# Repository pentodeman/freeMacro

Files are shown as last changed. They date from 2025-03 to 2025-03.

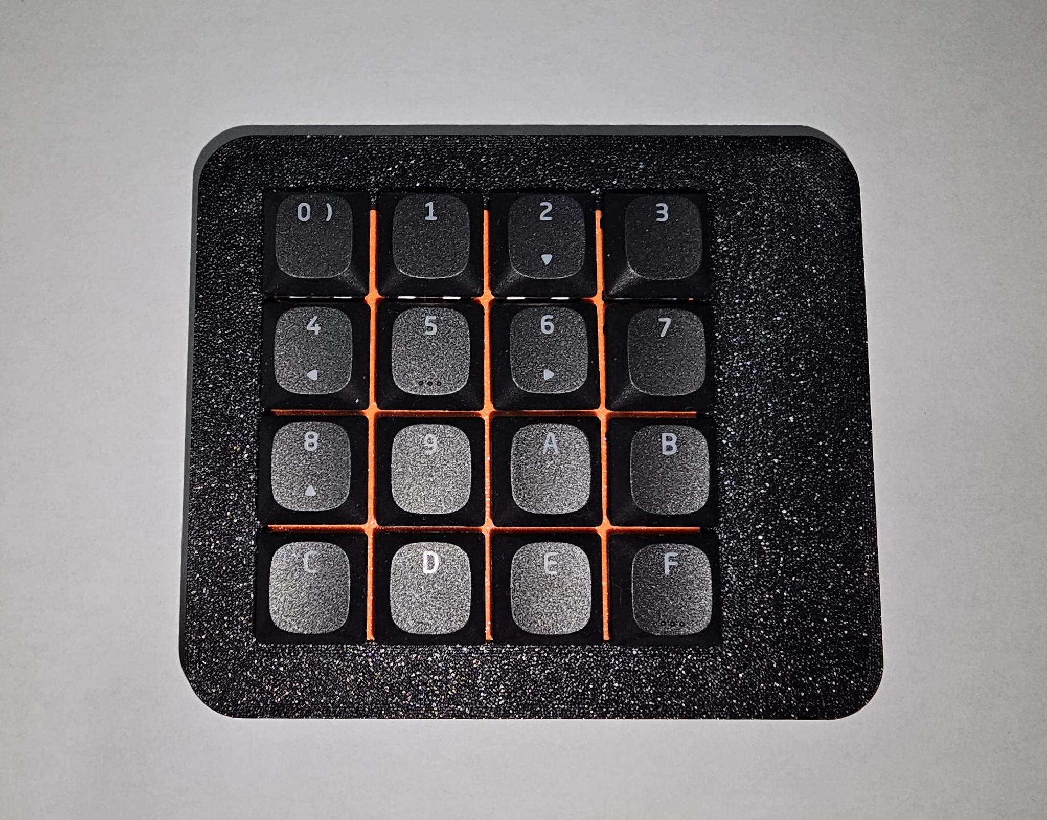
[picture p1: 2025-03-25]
images/Plate_Top_View.jpeg

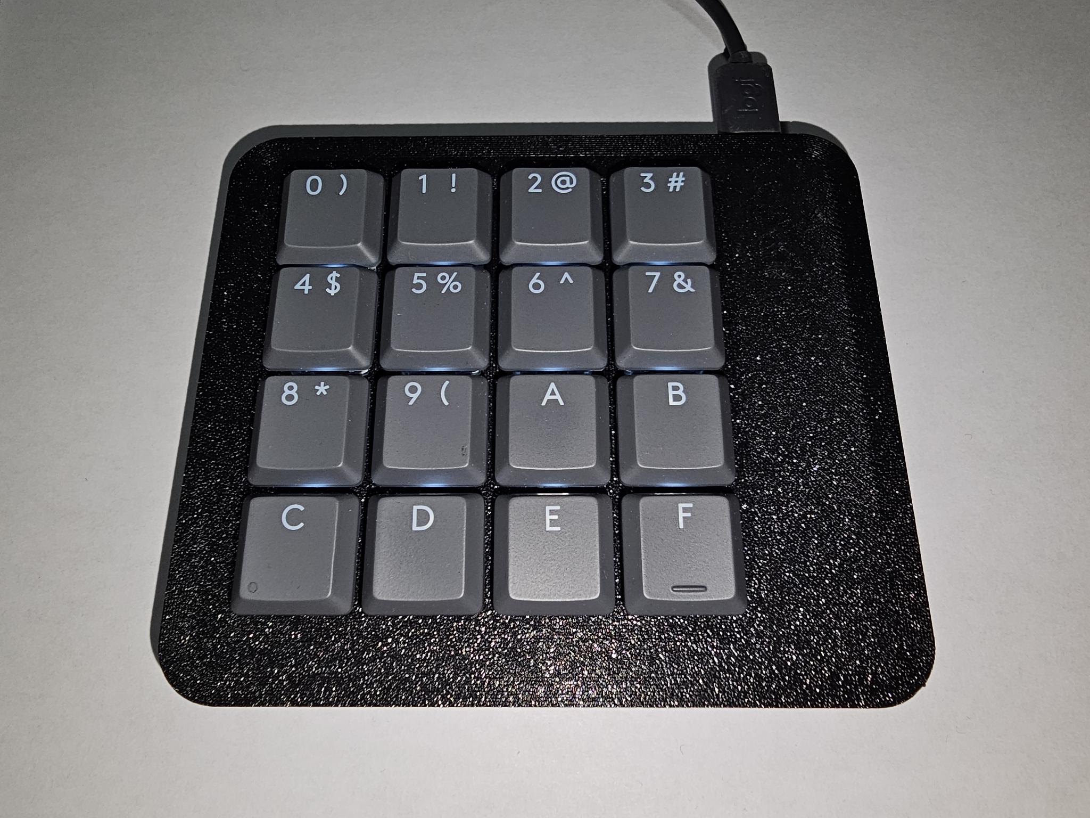
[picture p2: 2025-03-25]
images/Plateless_Top_Angle_View.jpeg

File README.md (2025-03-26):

# freeMacro rev. 1
A simple macro keypad that invokes key combinations, prints strings of text, and types special characters.

Special thanks to Arduino LLC for providing the Keyboard library that was used to create this project.
The library is available under:
https://github.com/arduino-libraries/Keyboard

## Features
* Typing strings, invoking macros, and typing special characters from the Unicode table
* 13 assignable banks with combinations of all three types of keypresses
* On the fly assignment of target operating system (Linux, Windows, macOS)
* Dependency free, plug and play
* Config generation handled by genConfig

## Default Firmware Behavior
* On power on, the board will flash each LED individually from the F key to the 0 key.
* Idle backlight should be steady without any flickering.
* On each keypress, only that key will be lit. Others will not.
* Holding down any key from 0 to C changes the current bank to that of they key held down.
* Pressing a key will invoke its macro (key combo, string, or Unicode).
* Holding down keys from D to F will change the target operating system:
  * D: Linux
  * E: Windows
  * F: macOS
* The default config initializes the bank to 9 and OS to Linux, if you prefer to use another combination, edit "banks.layout" and run genConfig (more instructions later).
* Bank and OS changes are indicated by the flash pattern:
  * fast: bank change
  * slow: OS change

## Modifying the config
* The firmware consists of two files:
  * freeMacro-firmware.ino: main firmware file that handles the logic
  * config.h: header file that houses all the functions called on keystrokes -> this is the config file
* Option 1: you can edit config.h directly if you want more control over your device (make sure to back up the default config in case of a rollback).
* Option 2: use genConfig and edit the soft config file (banks.layout).

## Arduino IDE is required for uploading the firmware (or Arduino CLI)
* Pro Micro boards are usually miniaturized Arduino Leonardos, selecting Arduino Leonardo in your board manager will likely work.
* In case of upload issues, make sure you selected the correct board and plugged it in. Communication issues can be caused by the serial port being busy or not having permissions to use the port (Googling the programmer error will usually solve the issue).

## Using genConfig
* This repo provides the source code for genConfig and a Linux binary.
* This program was only tested on Linux. Windows or macOS users may need to make changes to the source code, but this is unlikely. If you're using one of these systems, try compiling it first. For this you will need a C++ compiler. I used g++.
* Compiling genConfig from source:
  * This program does not use any third-party dependencies.
  * The only requirement for compilation is the C++ compiler itself; g++ is recommended.
  * To compile the program, follow these steps:
  
    ```git clone https://github.com/pentodeman/freeMacro```
    
    ```cd freeMacro```

    ```g++ genConfig.cpp -o genConfig```

    ```./genConfig --help```
  * It is not recommended to add genConfig to any binary directories (/bin, /sbin, /usr/bin, /usr/sbin, etc...) as the program outputs the file to its current working directory.
  * genConfig will look for the file called banks.layout in its current working directory and will output config.h
  * To generate a new config simply run:

    ```./genConfig``` for silent generation

    or

    ```./genConfig -v``` or ```./genConfig --verbose``` for verbose generation.
  * To use the new config, move the new config.h to the "freeMacro-firmware" directory and replace the old one (backing up your configs is recommended).
  * Once the new config.h is placed in the firmware directory, open the .ino file in Arduino IDE and upload it to your freeMacro board.
  * Instructions for modifying banks.layout are in the file itself and include a general template with all possible keywords.

## Assembly
* Required materials:
  * 1 PCB **make sure the PCB thickness is 1.6 mm** (Gerber files attached)
  * 16 3-pin full size mechanical switches of any kind (5-pin update coming soon in revision 2)
  * Electronic components listed in the BOM
  * 3D printed case (.stl files attached; feel free to design your own (.step file of the PCB can be generated in KiCad))
  * Low profile keycaps (currently full size keycaps have clearance issues with the enclosure)
* Tips for soldering the PCB:
  1. Start with the smallest and most repetitive components first (all passive and discrete components on the top plane).
  2. Solder the two multiplexer ICs.
  3. Clean the PCB thoroughly with isopropanol.
  4. Then solder the bottom LED current limiting resistors and clean the board again.
  5. Solder the Arduino Pro Micro FLUSH with the PCB. The case is designed to fit the microcontroller soldered directly to the PCB using included headers (see images folder).
    * feed the headers from the bottom of the freeMacro PCB and place the Arduino on top.
  6. After all electronic components are soldered, test the board by bridging switch pads with tweezers or any other conductor. Open any text editor and check if all characters are printed. Bank 9 of the default config is a good test.
  7. Once everything works, solder the switches. If you use the top shell with the plate, print the plate first and populate it with switches. It works as a good soldering guide. Make sure to test fit the entire device before soldering the switches.
  8. After soldering the switches, feed the LEDs throughand solder them. It's a good idea to just feed them and bend the leads for testing. Do it and plug in the board. If you see all LEDs shining (with some wiggling due to the lack of solder), the board works.
  9. Trim the leads, clean the board one last time, and assemble the case.
  10. Your board is ready, it's a good time to double check everything.

### Please note that this project is not a polished product. It's meant to be a fun project to tinker and experiment with. Working on it took me a total of one week worth of deisgn, coding, assembly, and testing. Please take imperfections with a grain of salt, as this is only a project delivered by a nerd to his fellow nerds. Happy tinkering!

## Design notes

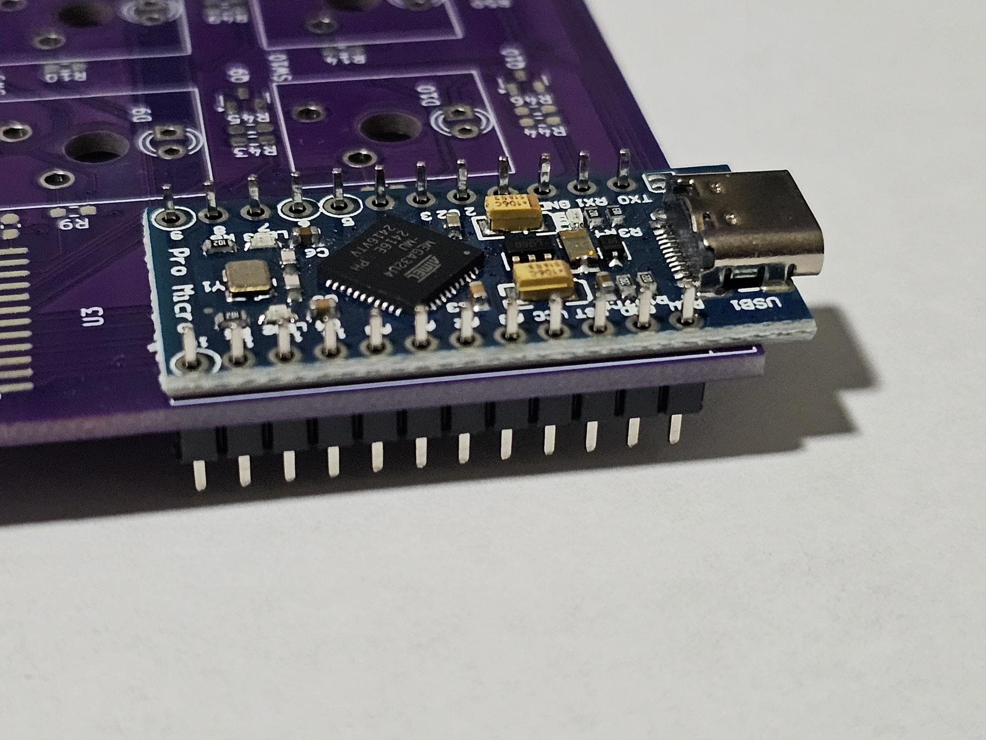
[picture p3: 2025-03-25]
images/Microcontroller_Placement.jpeg

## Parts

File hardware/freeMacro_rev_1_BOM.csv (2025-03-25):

Reference | Value | Datasheet | Footprint | Qty | DNP
C1,C2 | 100nF | ~ | Capacitor_SMD:C_0603_1608Metric_Pad1.08x0.95mm_HandSolder | 2
D1,D2,D3,D4,D5,D6,D7,D8,D9,D10,D11,D12,D13,D14,D15,D16 | LED | ~ | LED_THT:LED_D3.0mm | 16
Q1,Q2,Q3,Q4,Q5,Q6,Q7,Q8,Q9,Q10,Q11,Q12,Q13,Q14,Q15,Q16 | 2N7002 | https://www.onsemi.com/pub/Collateral/NDS7002A-D.PDF | Package_TO_SOT_SMD:SOT-23 | 16
R1,R2,R3,R4,R5,R6,R7,R8,R9,R10,R11,R12,R13,R14,R15,R16,R17,R18 | 10k | ~ | Resistor_SMD:R_0603_1608Metric_Pad0.98x0.95mm_HandSolder | 18
R19,R23,R26,R29,R32,R35,R38,R41,R45,R46,R51,R52,R57,R58,R63,R64 | 100k | ~ | Resistor_SMD:R_0603_1608Metric_Pad0.98x0.95mm_HandSolder | 16
R20,R22,R25,R28,R31,R34,R37,R40,R43,R44,R49,R50,R55,R56,R61,R62 | 10 | ~ | Resistor_SMD:R_0603_1608Metric_Pad0.98x0.95mm_HandSolder | 16
R21,R24,R27,R30,R33,R36,R39,R42,R47,R48,R53,R54,R59,R60,R65,R66 | 200 | ~ | Resistor_SMD:R_0603_1608Metric_Pad0.98x0.95mm_HandSolder | 16
U1,U2 | CD74HC4067M | http://www.ti.com/lit/ds/symlink/cd74hc4067.pdf | Package_SO:SOIC-24W_7.5x15.4mm_P1.27mm | 2

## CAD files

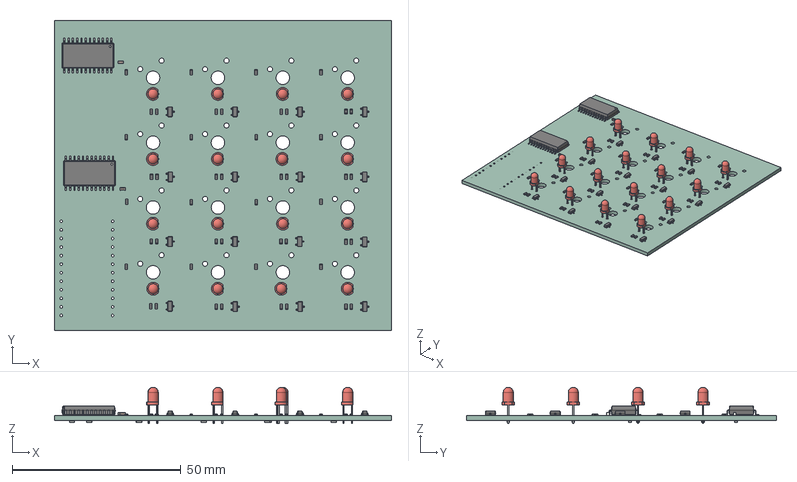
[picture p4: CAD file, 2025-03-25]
enclosure/freeMacro_rev_1_board.step
100.0 x 92.0 x 10.8 mm
R_0603_1608Metric x 66
LED_D3.0mm x 16
SOT-23 x 16
SOIC-24W_7.5x15.4mm_P1.27mm x 2
C_0603_1608Metric x 2
Macro Keyboard V1_PCB

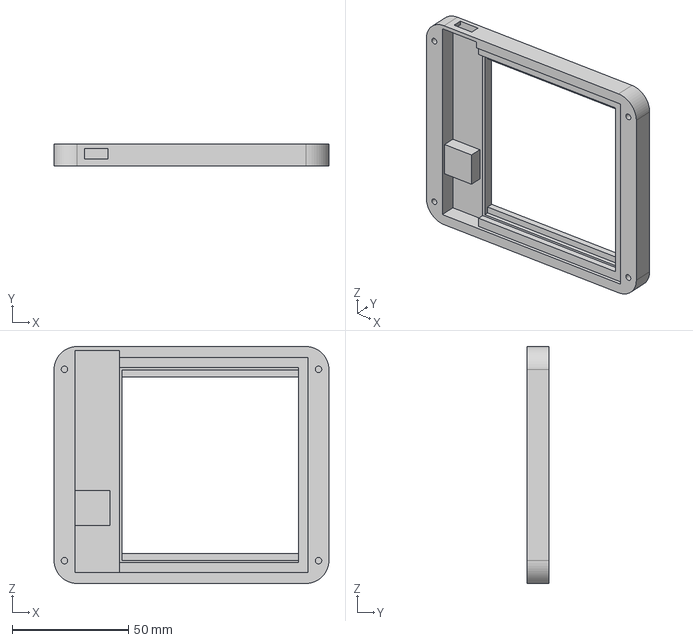
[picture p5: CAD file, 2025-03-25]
enclosure/Case Top.step
118.4 x 9.64 x 102.0 mm

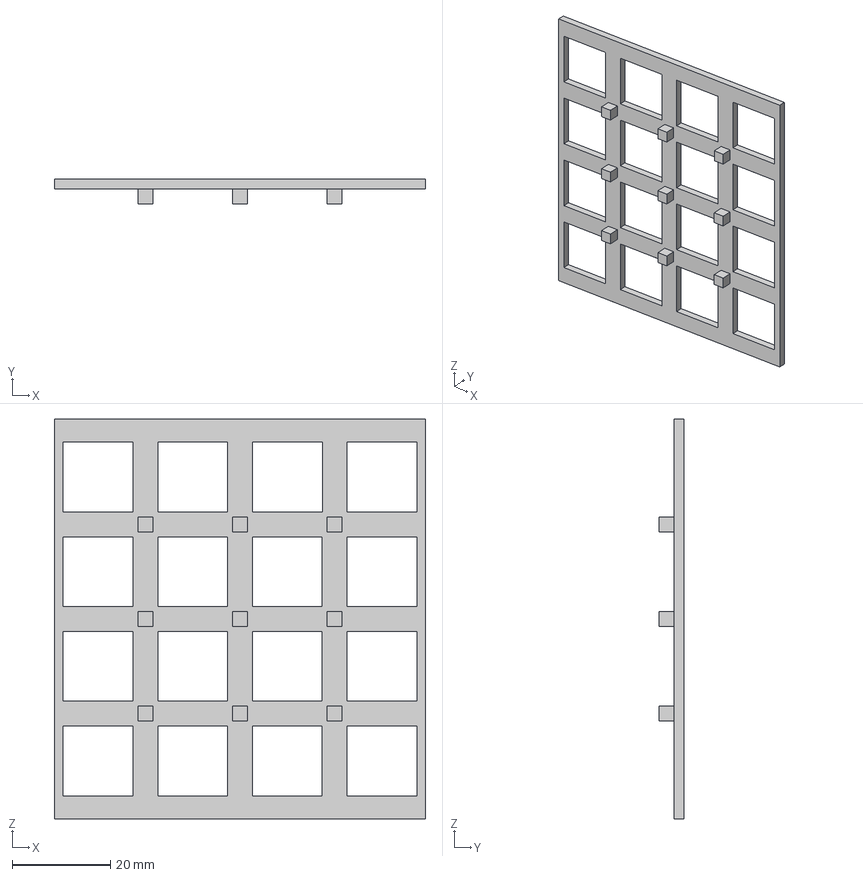
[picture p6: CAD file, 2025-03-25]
enclosure/Plate.step
75.5 x 5.00 x 81.3 mm

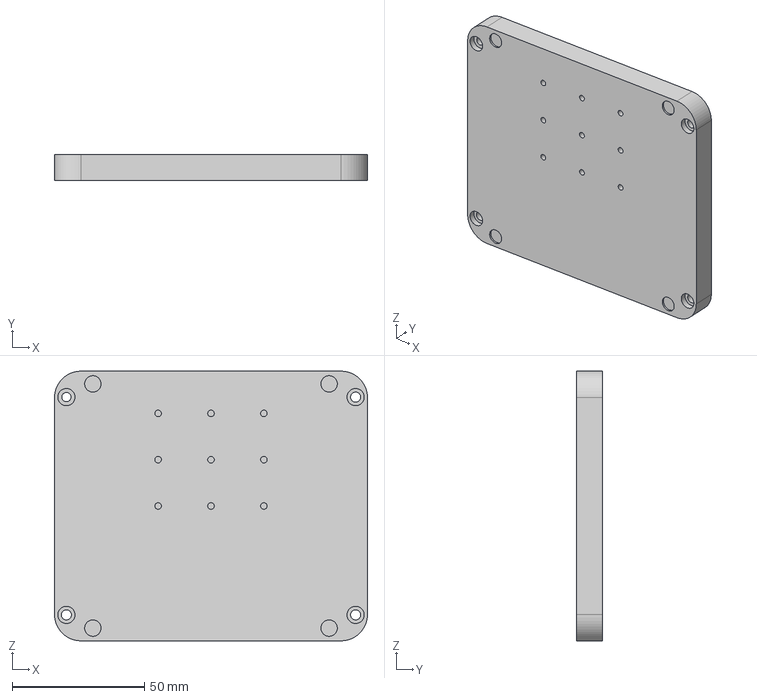
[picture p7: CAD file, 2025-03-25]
enclosure/Case Bottom.step
118.4 x 10.0 x 102.0 mm

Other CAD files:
enclosure/Case Bottom.stl
enclosure/Case Top.stl
enclosure/Plate.stl

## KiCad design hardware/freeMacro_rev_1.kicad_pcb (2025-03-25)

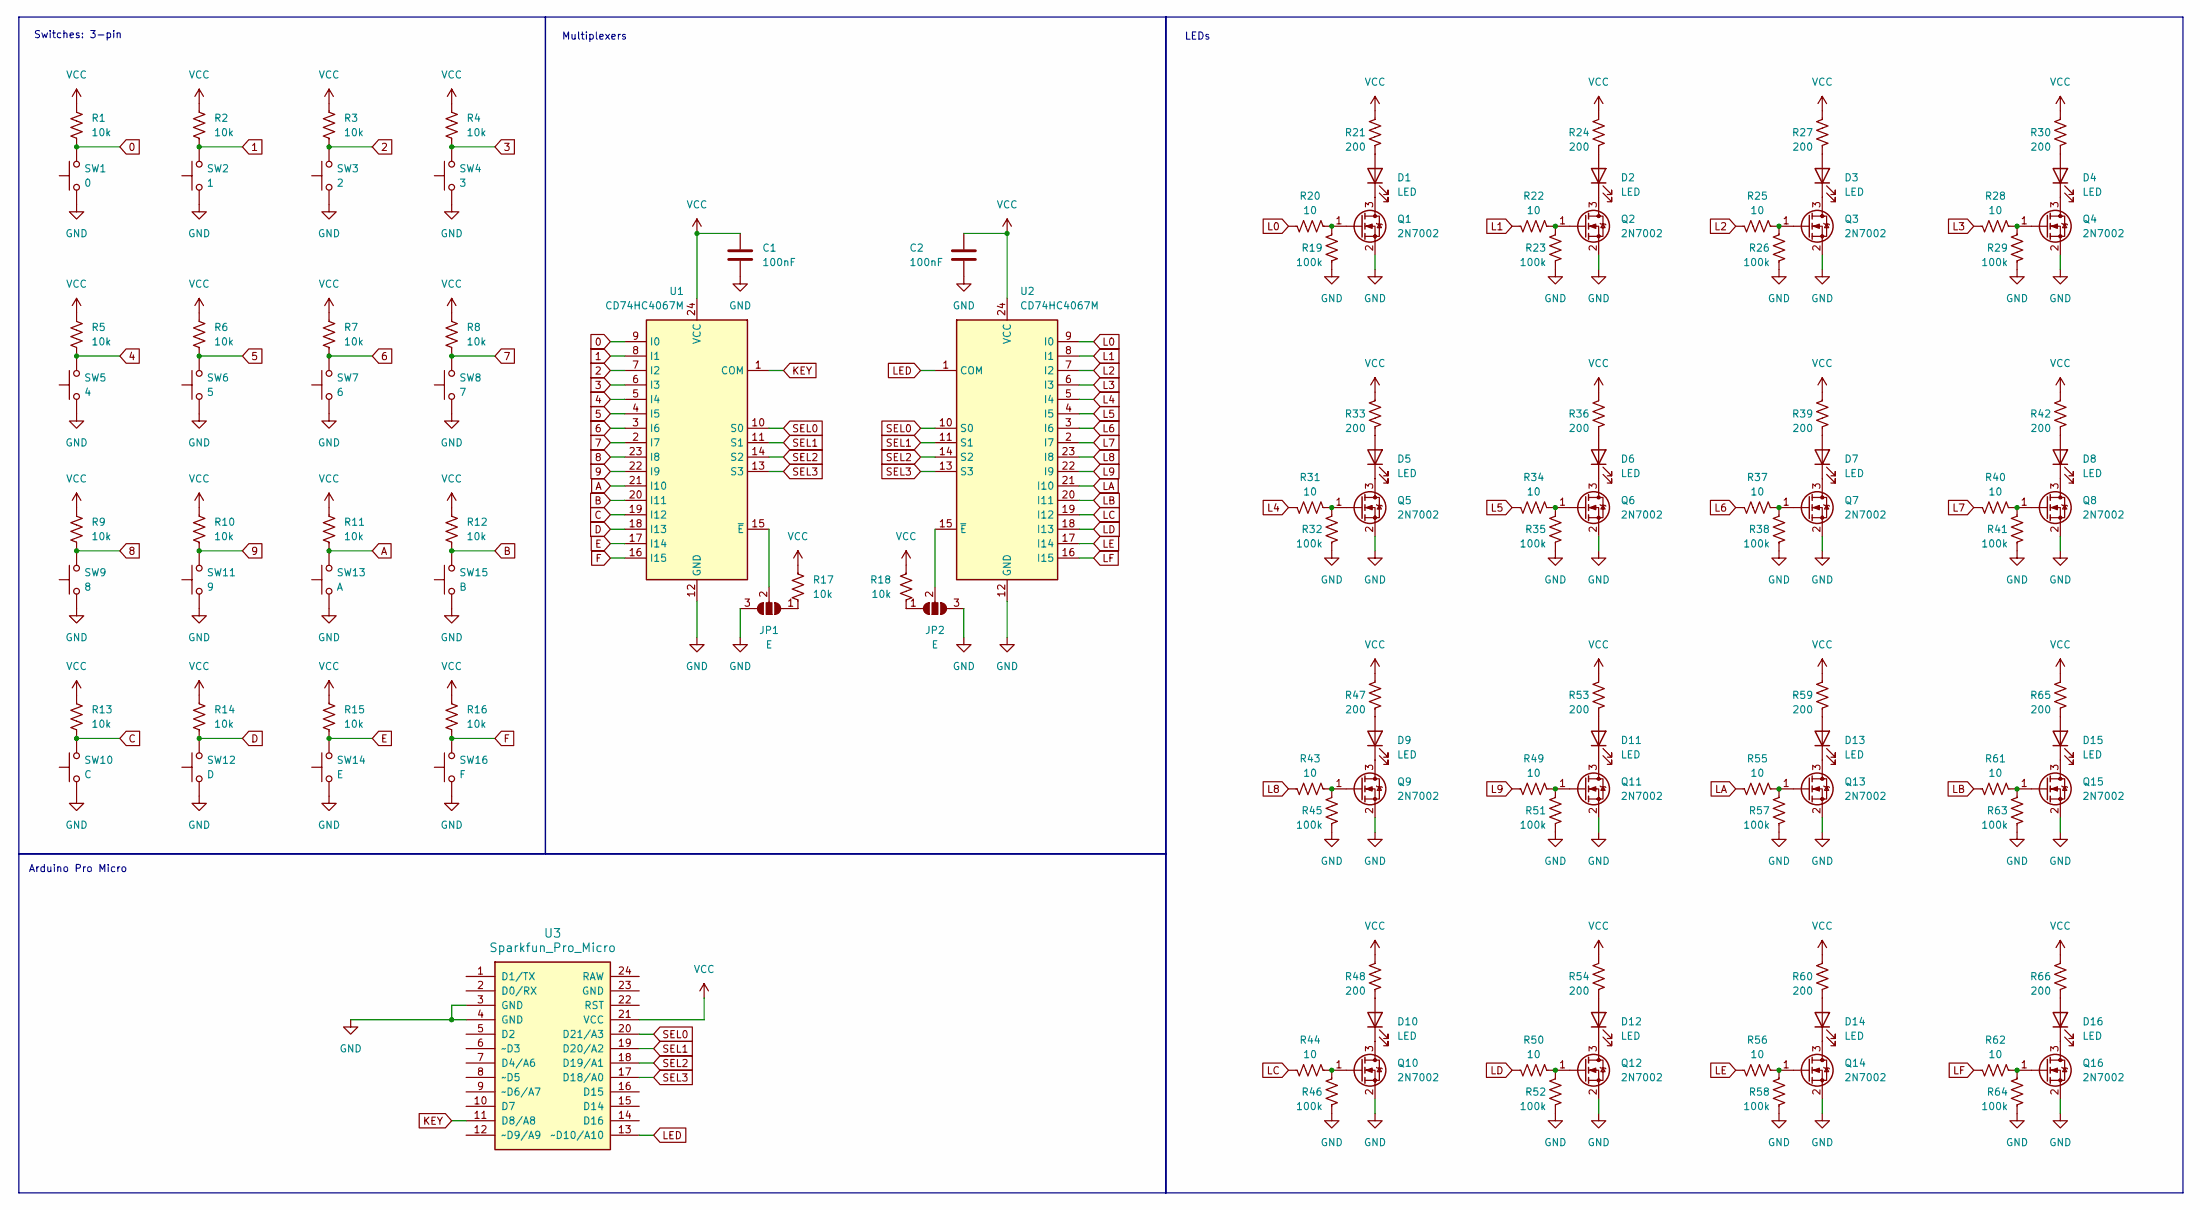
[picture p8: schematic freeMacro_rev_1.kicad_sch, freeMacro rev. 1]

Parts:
C1, C2: 100nF; C_0603_1608Metric_Pad1.08x0.95mm_HandSolder
D1, D2, D3, D4, D5, D6, D7, D8, D9, D10, D11, D12, D13, D14, D15, D16: LED; LED_D3.0mm
JP1, JP2: E; SolderJumper-3_P2.0mm_Open_TrianglePad1.0x1.5mm
Q1, Q2, Q3, Q4, Q5, Q6, Q7, Q8, Q9, Q10, Q11, Q12, Q13, Q14, Q15, Q16: 2N7002; SOT-23
R1, R2, R3, R4, R5, R6, R7, R8, R9, R10, R11, R12, R13, R14, R15, R16, R17, R18: 10k; R_0603_1608Metric_Pad0.98x0.95mm_HandSolder
R19, R23, R26, R29, R32, R35, R38, R41, R45, R46, R51, R52, R57, R58, R63, R64: 100k; R_0603_1608Metric_Pad0.98x0.95mm_HandSolder
R20, R22, R25, R28, R31, R34, R37, R40, R43, R44, R49, R50, R55, R56, R61, R62: 10; R_0603_1608Metric_Pad0.98x0.95mm_HandSolder
R21, R24, R27, R30, R33, R36, R39, R42, R47, R48, R53, R54, R59, R60, R65, R66: 200; R_0603_1608Metric_Pad0.98x0.95mm_HandSolder
SW1: 0; SW_Cherry_MX_1.00u_Plate
SW2: 1; SW_Cherry_MX_1.00u_Plate
SW3: 2; SW_Cherry_MX_1.00u_Plate
SW4: 3; SW_Cherry_MX_1.00u_Plate
SW5: 4; SW_Cherry_MX_1.00u_Plate
SW6: 5; SW_Cherry_MX_1.00u_Plate
SW7: 6; SW_Cherry_MX_1.00u_Plate
SW8: 7; SW_Cherry_MX_1.00u_Plate
SW9: 8; SW_Cherry_MX_1.00u_Plate
SW10: C; SW_Cherry_MX_1.00u_Plate
SW11: 9; SW_Cherry_MX_1.00u_Plate
SW12: D; SW_Cherry_MX_1.00u_Plate
SW13: A; SW_Cherry_MX_1.00u_Plate
SW14: E; SW_Cherry_MX_1.00u_Plate
SW15: B; SW_Cherry_MX_1.00u_Plate
SW16: F; SW_Cherry_MX_1.00u_Plate
U1, U2: CD74HC4067M; SOIC-24W_7.5x15.4mm_P1.27mm
U3: Sparkfun_Pro_Micro

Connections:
0: R1.2, SW1.2, U1.9 (I0)
1: R2.2, SW2.2, U1.8 (I1)
2: R3.2, SW3.2, U1.7 (I2)
3: R4.2, SW4.2, U1.6 (I3)
4: R5.2, SW5.2, U1.5 (I4)
5: R6.2, SW6.2, U1.4 (I5)
6: R7.2, SW7.2, U1.3 (I6)
7: R8.2, SW8.2, U1.2 (I7)
8: R9.2, SW9.2, U1.23 (I8)
9: R10.2, SW11.2, U1.22 (I9)
A: R11.2, SW13.2, U1.21 (I10)
B: R12.2, SW15.2, U1.20 (I11)
C: R13.2, SW10.2, U1.19 (I12)
D: R14.2, SW12.2, U1.18 (I13)
E: R15.2, SW14.2, U1.17 (I14)
F: R16.2, SW16.2, U1.16 (I15)
GND: C1.2, C2.2, JP1.3 (B), JP2.3 (B), Q1.2 (S), Q2.2 (S), Q3.2 (S), Q4.2 (S), Q5.2 (S), Q6.2 (S), Q7.2 (S), Q8.2 (S), Q9.2 (S), Q10.2 (S), Q11.2 (S), Q12.2 (S), Q13.2 (S), Q14.2 (S), Q15.2 (S), Q16.2 (S), R19.2, R23.2, R26.2, R29.2, R32.2, R35.2, R38.2, R41.2, R45.2, R46.2, R51.2, R52.2, R57.2, R58.2, R63.2, R64.2, SW1.1, SW2.1, SW3.1, SW4.1, SW5.1, SW6.1, SW7.1, SW8.1, SW9.1, SW10.1, SW11.1, SW12.1, SW13.1, SW14.1, SW15.1, SW16.1, U1.12 (GND), U2.12 (GND), U3.3 (GND), U3.4 (GND)
KEY: U1.1 (COM), U3.11 (D8/A8)
L0: R20.1, U2.9 (I0)
L1: R22.1, U2.8 (I1)
L2: R25.1, U2.7 (I2)
L3: R28.1, U2.6 (I3)
L4: R31.1, U2.5 (I4)
L5: R34.1, U2.4 (I5)
L6: R37.1, U2.3 (I6)
L7: R40.1, U2.2 (I7)
L8: R43.1, U2.23 (I8)
L9: R49.1, U2.22 (I9)
LA: R55.1, U2.21 (I10)
LB: R61.1, U2.20 (I11)
LC: R44.1, U2.19 (I12)
LD: R50.1, U2.18 (I13)
LE: R56.1, U2.17 (I14)
LED: U2.1 (COM), U3.13 (~D10/A10)
LF: R62.1, U2.16 (I15)
unnamed: D1.2 (A), R21.2
unnamed: D1.1 (K), Q1.3 (D)
unnamed: D2.2 (A), R24.2
unnamed: D2.1 (K), Q2.3 (D)
unnamed: D3.2 (A), R27.2
unnamed: D3.1 (K), Q3.3 (D)
unnamed: D4.2 (A), R30.2
unnamed: D4.1 (K), Q4.3 (D)
unnamed: D5.2 (A), R33.2
unnamed: D5.1 (K), Q5.3 (D)
unnamed: D6.2 (A), R36.2
unnamed: D6.1 (K), Q6.3 (D)
unnamed: D7.2 (A), R39.2
unnamed: D7.1 (K), Q7.3 (D)
unnamed: D8.2 (A), R42.2
unnamed: D8.1 (K), Q8.3 (D)
unnamed: D9.2 (A), R47.2
unnamed: D9.1 (K), Q9.3 (D)
unnamed: D10.2 (A), R48.2
unnamed: D10.1 (K), Q10.3 (D)
unnamed: D11.2 (A), R53.2
unnamed: D11.1 (K), Q11.3 (D)
unnamed: D12.2 (A), R54.2
unnamed: D12.1 (K), Q12.3 (D)
unnamed: D13.2 (A), R59.2
unnamed: D13.1 (K), Q13.3 (D)
unnamed: D14.2 (A), R60.2
unnamed: D14.1 (K), Q14.3 (D)
unnamed: D15.2 (A), R65.2
unnamed: D15.1 (K), Q15.3 (D)
unnamed: D16.2 (A), R66.2
unnamed: D16.1 (K), Q16.3 (D)
unnamed: JP1.1 (A), R17.2
unnamed: JP1.2 (C), U1.15 (~E)
unnamed: JP2.1 (A), R18.2
unnamed: JP2.2 (C), U2.15 (~E)
unnamed: Q1.1 (G), R19.1, R20.2
unnamed: Q2.1 (G), R22.2, R23.1
unnamed: Q3.1 (G), R25.2, R26.1
unnamed: Q4.1 (G), R28.2, R29.1
unnamed: Q5.1 (G), R31.2, R32.1
unnamed: Q6.1 (G), R34.2, R35.1
unnamed: Q7.1 (G), R37.2, R38.1
unnamed: Q8.1 (G), R40.2, R41.1
unnamed: Q9.1 (G), R43.2, R45.1
unnamed: Q10.1 (G), R44.2, R46.1
unnamed: Q11.1 (G), R49.2, R51.1
unnamed: Q12.1 (G), R50.2, R52.1
unnamed: Q13.1 (G), R55.2, R57.1
unnamed: Q14.1 (G), R56.2, R58.1
unnamed: Q15.1 (G), R61.2, R63.1
unnamed: Q16.1 (G), R62.2, R64.1
SEL0: U1.10 (S0), U2.10 (S0), U3.20 (D21/A3)
SEL1: U1.11 (S1), U2.11 (S1), U3.19 (D20/A2)
SEL2: U1.14 (S2), U2.14 (S2), U3.18 (D19/A1)
SEL3: U1.13 (S3), U2.13 (S3), U3.17 (D18/A0)
VCC: C1.1, C2.1, R1.1, R2.1, R3.1, R4.1, R5.1, R6.1, R7.1, R8.1, R9.1, R10.1, R11.1, R12.1, R13.1, R14.1, R15.1, R16.1, R17.1, R18.1, R21.1, R24.1, R27.1, R30.1, R33.1, R36.1, R39.1, R42.1, R47.1, R48.1, R53.1, R54.1, R59.1, R60.1, R65.1, R66.1, U1.24 (VCC), U2.24 (VCC), U3.21 (VCC)

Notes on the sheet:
Multiplexers
Switches: 3-pin
LEDs
Arduino Pro Micro

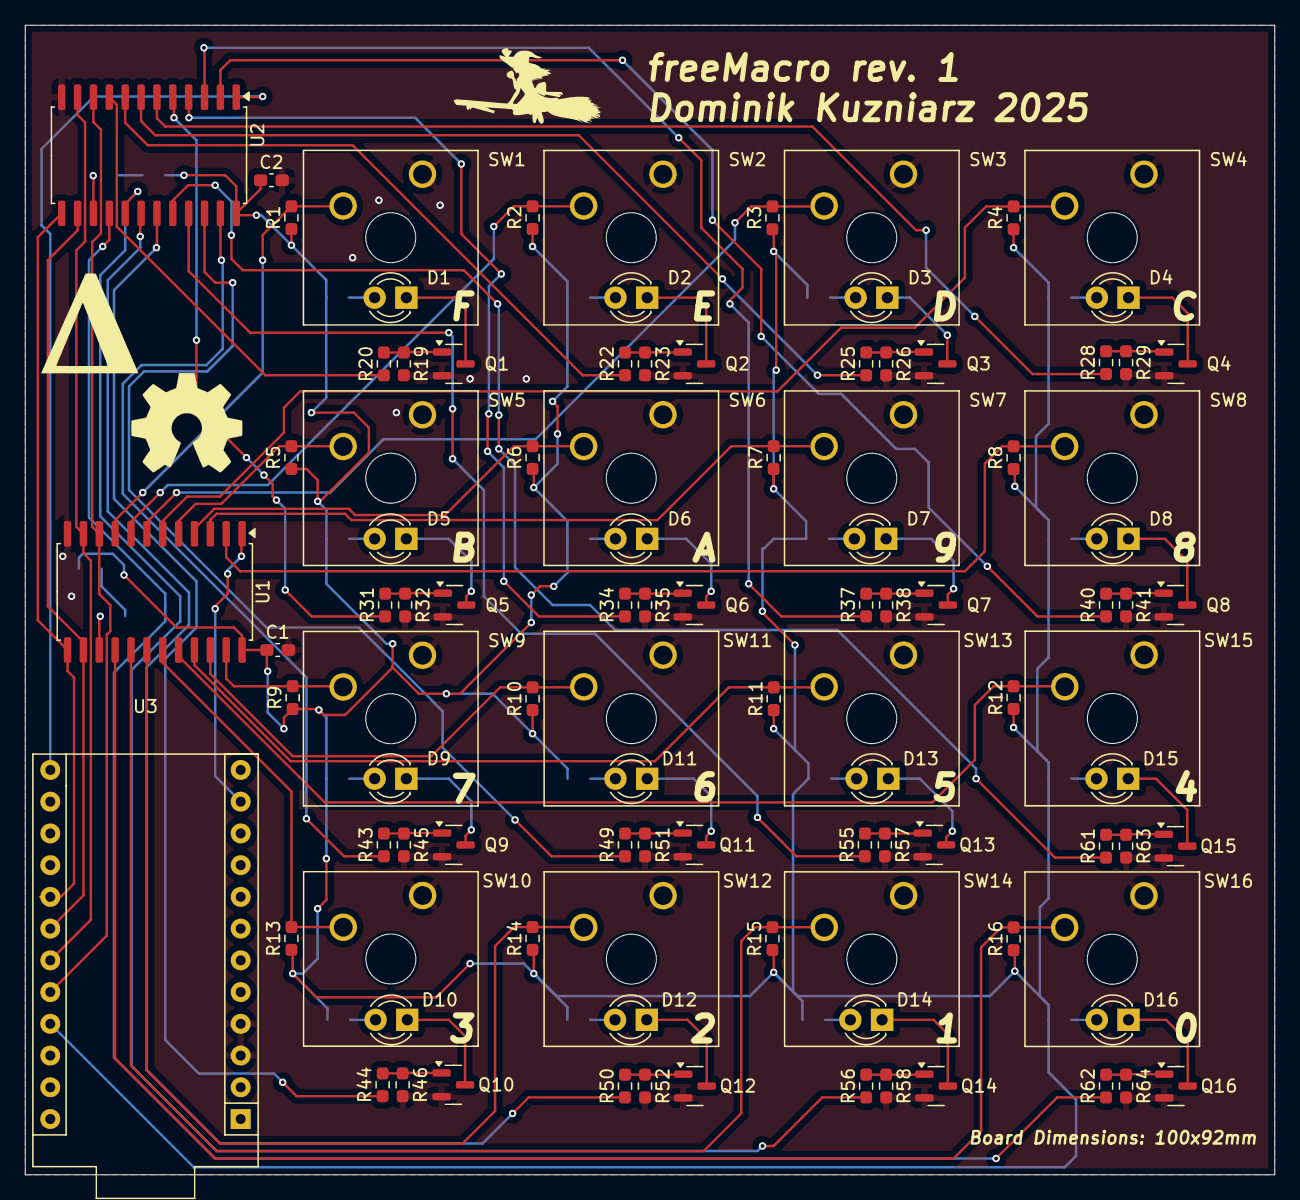
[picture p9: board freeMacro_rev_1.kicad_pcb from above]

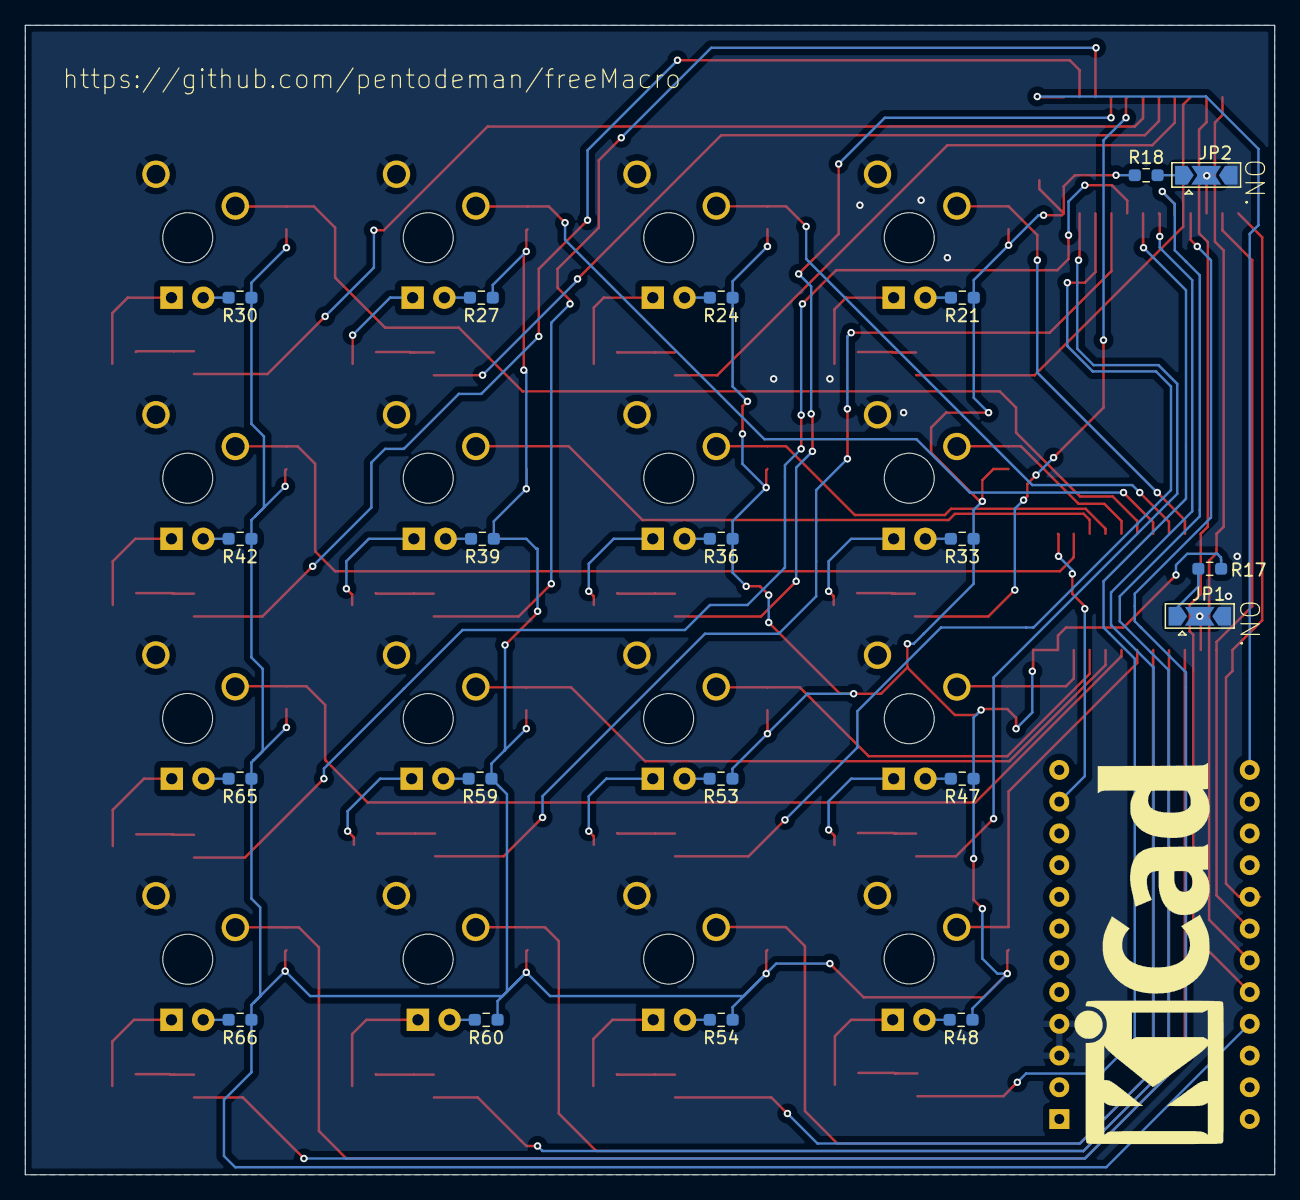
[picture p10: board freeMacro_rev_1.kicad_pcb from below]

Board: 2 copper layers, 100.0 x 92.0 mm, 121 parts (20 on the bottom side), 92 nets.

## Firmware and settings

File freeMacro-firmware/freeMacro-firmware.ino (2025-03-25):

// freeMacro firmware v0.5
// Dominik Kuzniarz 2025

#include "config.h"
#include "Keyboard.h"
#define LEDOUT 10
#define KEYIN 8

long lastKeyTime = 0;
long currentKeyTime = 0;

void animation(){
  for(uint8_t i = 0; i < 16; i++){
    uint8_t select = i << 4;
    PORTF = select;
    uint8_t brt;
    for(brt = 0; brt < 255; brt++){
      analogWrite(LEDOUT, brt);
      delayMicroseconds(50);
    }
    for(brt = 255; brt > 0; brt--){
      analogWrite(LEDOUT, brt);
      delayMicroseconds(500);
    }
  }
}

void bankFlash(uint8_t sel){
  uint8_t select = sel << 4;
  PORTF = select;
  for(uint8_t i = 0; i < 7; i++){
    uint8_t brt;
    for(brt = 0; brt < 255; brt++){
      analogWrite(LEDOUT, brt);
      delayMicroseconds(400);
    }
    for(brt = 255; brt > 0; brt--){
      analogWrite(LEDOUT, brt);
      delayMicroseconds(400);
    }
  }
}

void bankFlashOS(uint8_t sel){
  uint8_t select = sel << 4;
  PORTF = select;
  for(uint8_t i = 0; i < 5; i++){
    uint8_t brt;
    for(brt = 0; brt < 255; brt++){
      analogWrite(LEDOUT, brt);
      delayMicroseconds(2000);
    }
    for(brt = 255; brt > 0; brt--){
      analogWrite(LEDOUT, brt);
      delayMicroseconds(10);
    }
  }
}

void bankSelectFeedback(uint8_t bank){
  switch(bank){
    case 0x00: bankFlash(0x00); break;
    case 0x01: bankFlash(0x01); break;
    case 0x02: bankFlash(0x02); break;
    case 0x03: bankFlash(0x03); break;
    case 0x04: bankFlash(0x04); break;
    case 0x05: bankFlash(0x05); break;
    case 0x06: bankFlash(0x06); break;
    case 0x07: bankFlash(0x07); break;
    case 0x08: bankFlash(0x08); break;
    case 0x09: bankFlash(0x09); break;
    case 0x0A: bankFlash(0x0A); break;
    case 0x0B: bankFlash(0x0B); break;
    case 0x0C: bankFlash(0x0C); break;
    case 0x0D: bankFlash(0x0D); break;
    case 0x0E: bankFlash(0x0E); break;
    case 0x0F: bankFlash(0x0F); break;
  }
}

void key(uint8_t keyPressed){
  lastKeyTime = millis();
  while(digitalRead(KEYIN) == LOW){
    currentKeyTime = millis();
    if(currentKeyTime - lastKeyTime >= HOLD_THRESHOLD){
      currentKeyTime = 0;
      lastKeyTime = 0;
      checkKeyHold(keyPressed);
    }
  }
  if(currentKeyTime - lastKeyTime >= DEBOUNCE_TIME){
    currentKeyTime = 0;
    lastKeyTime = 0;
    checkKeyPress(keyPressed);
  }
}

void setup() {
  pinMode(LEDOUT, OUTPUT);
  pinMode(KEYIN, INPUT);
  DDRF = DDRF | 0xFF;          // set all PF pins as output
  Keyboard.begin();
  animation();
}

void checkKeyHold(uint8_t sel){
  switch(sel){
    case 0x00: currentOS = 0x02; bankFlashOS(0x00); break;
    case 0x01: currentOS = 0x01; bankFlashOS(0x01); break;
    case 0x02: currentOS = 0x00; bankFlashOS(0x02); break;
    case 0x03: currentBank = 0x0C; bankSelectFeedback(0x03); break;
    case 0x04: currentBank = 0x0B; bankSelectFeedback(0x04); break;
    case 0x05: currentBank = 0x0A; bankSelectFeedback(0x05); break;
    case 0x06: currentBank = 0x09; bankSelectFeedback(0x06); break;
    case 0x07: currentBank = 0x08; bankSelectFeedback(0x07); break;
    case 0x08: currentBank = 0x07; bankSelectFeedback(0x08); break;
    case 0x09: currentBank = 0x06; bankSelectFeedback(0x09); break;
    case 0x0A: currentBank = 0x05; bankSelectFeedback(0x0A); break;
    case 0x0B: currentBank = 0x04; bankSelectFeedback(0x0B); break;
    case 0x0C: currentBank = 0x03; bankSelectFeedback(0x0C); break;
    case 0x0D: currentBank = 0x02; bankSelectFeedback(0x0D); break;
    case 0x0E: currentBank = 0x01; bankSelectFeedback(0x0E); break;
    case 0x0F: currentBank = 0x00; bankSelectFeedback(0x0F); break;
  }
}

void checkKeyPress(uint8_t sel){
  switch(currentBank){
    case 0:
      switch(sel){
        case 0x00: bank0(sel, currentOS); break;
        case 0x01: bank0(sel, currentOS); break;
        case 0x02: bank0(sel, currentOS); break;
        case 0x03: bank0(sel, currentOS); break;
        case 0x04: bank0(sel, currentOS); break;
        case 0x05: bank0(sel, currentOS); break;
        case 0x06: bank0(sel, currentOS); break;
        case 0x07: bank0(sel, currentOS); break;
        case 0x08: bank0(sel, currentOS); break;
        case 0x09: bank0(sel, currentOS); break;
        case 0x0A: bank0(sel, currentOS); break;
        case 0x0B: bank0(sel, currentOS); break;
        case 0x0C: bank0(sel, currentOS); break;
        case 0x0D: bank0(sel, currentOS); break;
        case 0x0E: bank0(sel, currentOS); break;
        case 0x0F: bank0(sel, currentOS); break;
      }
      break;

    case 1:
      switch(sel){
        case 0x00: bank1(sel, currentOS); break;
        case 0x01: bank1(sel, currentOS); break;
        case 0x02: bank1(sel, currentOS); break;
        case 0x03: bank1(sel, currentOS); break;
        case 0x04: bank1(sel, currentOS); break;
        case 0x05: bank1(sel, currentOS); break;
        case 0x06: bank1(sel, currentOS); break;
        case 0x07: bank1(sel, currentOS); break;
        case 0x08: bank1(sel, currentOS); break;
        case 0x09: bank1(sel, currentOS); break;
        case 0x0A: bank1(sel, currentOS); break;
        case 0x0B: bank1(sel, currentOS); break;
        case 0x0C: bank1(sel, currentOS); break;
        case 0x0D: bank1(sel, currentOS); break;
        case 0x0E: bank1(sel, currentOS); break;
        case 0x0F: bank1(sel, currentOS); break;
      }
      break;

    case 2:
      switch(sel){
        case 0x00: bank2(sel, currentOS); break;
        case 0x01: bank2(sel, currentOS); break;
        case 0x02: bank2(sel, currentOS); break;
        case 0x03: bank2(sel, currentOS); break;
        case 0x04: bank2(sel, currentOS); break;
        case 0x05: bank2(sel, currentOS); break;
        case 0x06: bank2(sel, currentOS); break;
        case 0x07: bank2(sel, currentOS); break;
        case 0x08: bank2(sel, currentOS); break;
        case 0x09: bank2(sel, currentOS); break;
        case 0x0A: bank2(sel, currentOS); break;
        case 0x0B: bank2(sel, currentOS); break;
        case 0x0C: bank2(sel, currentOS); break;
        case 0x0D: bank2(sel, currentOS); break;
        case 0x0E: bank2(sel, currentOS); break;
        case 0x0F: bank2(sel, currentOS); break;
      }
      break;
      
    case 3:
      switch(sel){
        case 0x00: bank3(sel, currentOS); break;
        case 0x01: bank3(sel, currentOS); break;
        case 0x02: bank3(sel, currentOS); break;
        case 0x03: bank3(sel, currentOS); break;
        case 0x04: bank3(sel, currentOS); break;
        case 0x05: bank3(sel, currentOS); break;
        case 0x06: bank3(sel, currentOS); break;
        case 0x07: bank3(sel, currentOS); break;
        case 0x08: bank3(sel, currentOS); break;
        case 0x09: bank3(sel, currentOS); break;
        case 0x0A: bank3(sel, currentOS); break;
        case 0x0B: bank3(sel, currentOS); break;
        case 0x0C: bank3(sel, currentOS); break;
        case 0x0D: bank3(sel, currentOS); break;
        case 0x0E: bank3(sel, currentOS); break;
        case 0x0F: bank3(sel, currentOS); break;
      }
      break;

    case 4:
      switch(sel){
        case 0x00: bank4(sel, currentOS); break;
        case 0x01: bank4(sel, currentOS); break;
        case 0x02: bank4(sel, currentOS); break;
        case 0x03: bank4(sel, currentOS); break;
        case 0x04: bank4(sel, currentOS); break;
        case 0x05: bank4(sel, currentOS); break;
        case 0x06: bank4(sel, currentOS); break;
        case 0x07: bank4(sel, currentOS); break;
        case 0x08: bank4(sel, currentOS); break;
        case 0x09: bank4(sel, currentOS); break;
        case 0x0A: bank4(sel, currentOS); break;
        case 0x0B: bank4(sel, currentOS); break;
        case 0x0C: bank4(sel, currentOS); break;
        case 0x0D: bank4(sel, currentOS); break;
        case 0x0E: bank4(sel, currentOS); break;
        case 0x0F: bank4(sel, currentOS); break;
      }
      break;

    case 5:
      switch(sel){
        case 0x00: bank5(sel, currentOS); break;
        case 0x01: bank5(sel, currentOS); break;
        case 0x02: bank5(sel, currentOS); break;
        case 0x03: bank5(sel, currentOS); break;
        case 0x04: bank5(sel, currentOS); break;
        case 0x05: bank5(sel, currentOS); break;
        case 0x06: bank5(sel, currentOS); break;
        case 0x07: bank5(sel, currentOS); break;
        case 0x08: bank5(sel, currentOS); break;
        case 0x09: bank5(sel, currentOS); break;
        case 0x0A: bank5(sel, currentOS); break;
        case 0x0B: bank5(sel, currentOS); break;
        case 0x0C: bank5(sel, currentOS); break;
        case 0x0D: bank5(sel, currentOS); break;
        case 0x0E: bank5(sel, currentOS); break;
        case 0x0F: bank5(sel, currentOS); break;
      }
      break;

    case 6:
      switch(sel){
        case 0x00: bank6(sel, currentOS); break;
        case 0x01: bank6(sel, currentOS); break;
        case 0x02: bank6(sel, currentOS); break;
        case 0x03: bank6(sel, currentOS); break;
        case 0x04: bank6(sel, currentOS); break;
        case 0x05: bank6(sel, currentOS); break;
        case 0x06: bank6(sel, currentOS); break;
        case 0x07: bank6(sel, currentOS); break;
        case 0x08: bank6(sel, currentOS); break;
        case 0x09: bank6(sel, currentOS); break;
        case 0x0A: bank6(sel, currentOS); break;
        case 0x0B: bank6(sel, currentOS); break;
        case 0x0C: bank6(sel, currentOS); break;
        case 0x0D: bank6(sel, currentOS); break;
        case 0x0E: bank6(sel, currentOS); break;
        case 0x0F: bank6(sel, currentOS); break;
      }
      break;
      
    case 7:
      switch(sel){
        case 0x00: bank7(sel, currentOS); break;
        case 0x01: bank7(sel, currentOS); break;
        case 0x02: bank7(sel, currentOS); break;
        case 0x03: bank7(sel, currentOS); break;
        case 0x04: bank7(sel, currentOS); break;
        case 0x05: bank7(sel, currentOS); break;
        case 0x06: bank7(sel, currentOS); break;
        case 0x07: bank7(sel, currentOS); break;
        case 0x08: bank7(sel, currentOS); break;
        case 0x09: bank7(sel, currentOS); break;
        case 0x0A: bank7(sel, currentOS); break;
        case 0x0B: bank7(sel, currentOS); break;
        case 0x0C: bank7(sel, currentOS); break;
        case 0x0D: bank7(sel, currentOS); break;
        case 0x0E: bank7(sel, currentOS); break;
        case 0x0F: bank7(sel, currentOS); break;
      }
      break;

    case 8:
      switch(sel){
        case 0x00: bank8(sel, currentOS); break;
        case 0x01: bank8(sel, currentOS); break;
        case 0x02: bank8(sel, currentOS); break;
        case 0x03: bank8(sel, currentOS); break;
        case 0x04: bank8(sel, currentOS); break;
        case 0x05: bank8(sel, currentOS); break;
        case 0x06: bank8(sel, currentOS); break;
        case 0x07: bank8(sel, currentOS); break;
        case 0x08: bank8(sel, currentOS); break;
        case 0x09: bank8(sel, currentOS); break;
        case 0x0A: bank8(sel, currentOS); break;
        case 0x0B: bank8(sel, currentOS); break;
        case 0x0C: bank8(sel, currentOS); break;
        case 0x0D: bank8(sel, currentOS); break;
        case 0x0E: bank8(sel, currentOS); break;
        case 0x0F: bank8(sel, currentOS); break;
      }
      break;

    case 9:
      switch(sel){
        case 0x00: bank9(sel, currentOS); break;
        case 0x01: bank9(sel, currentOS); break;
        case 0x02: bank9(sel, currentOS); break;
        case 0x03: bank9(sel, currentOS); break;
        case 0x04: bank9(sel, currentOS); break;
        case 0x05: bank9(sel, currentOS); break;
        case 0x06: bank9(sel, currentOS); break;
        case 0x07: bank9(sel, currentOS); break;
        case 0x08: bank9(sel, currentOS); break;
        case 0x09: bank9(sel, currentOS); break;
        case 0x0A: bank9(sel, currentOS); break;
        case 0x0B: bank9(sel, currentOS); break;
        case 0x0C: bank9(sel, currentOS); break;
        case 0x0D: bank9(sel, currentOS); break;
        case 0x0E: bank9(sel, currentOS); break;
        case 0x0F: bank9(sel, currentOS); break;
      }
      break;

    case 10:
      switch(sel){
        case 0x00: bankA(sel, currentOS); break;
        case 0x01: bankA(sel, currentOS); break;
        case 0x02: bankA(sel, currentOS); break;
        case 0x03: bankA(sel, currentOS); break;
        case 0x04: bankA(sel, currentOS); break;
        case 0x05: bankA(sel, currentOS); break;
        case 0x06: bankA(sel, currentOS); break;
        case 0x07: bankA(sel, currentOS); break;
        case 0x08: bankA(sel, currentOS); break;
        case 0x09: bankA(sel, currentOS); break;
        case 0x0A: bankA(sel, currentOS); break;
        case 0x0B: bankA(sel, currentOS); break;
        case 0x0C: bankA(sel, currentOS); break;
        case 0x0D: bankA(sel, currentOS); break;
        case 0x0E: bankA(sel, currentOS); break;
        case 0x0F: bankA(sel, currentOS); break;
      }
      break;
      
    case 11:
      switch(sel){
        case 0x00: bankB(sel, currentOS); break;
        case 0x01: bankB(sel, currentOS); break;
        case 0x02: bankB(sel, currentOS); break;
        case 0x03: bankB(sel, currentOS); break;
        case 0x04: bankB(sel, currentOS); break;
        case 0x05: bankB(sel, currentOS); break;
        case 0x06: bankB(sel, currentOS); break;
        case 0x07: bankB(sel, currentOS); break;
        case 0x08: bankB(sel, currentOS); break;
        case 0x09: bankB(sel, currentOS); break;
        case 0x0A: bankB(sel, currentOS); break;
        case 0x0B: bankB(sel, currentOS); break;
        case 0x0C: bankB(sel, currentOS); break;
        case 0x0D: bankB(sel, currentOS); break;
        case 0x0E: bankB(sel, currentOS); break;
        case 0x0F: bankB(sel, currentOS); break;
      }
      break;

    case 12:
      switch(sel){
        case 0x00: bankC(sel, currentOS); break;
        case 0x01: bankC(sel, currentOS); break;
        case 0x02: bankC(sel, currentOS); break;
        case 0x03: bankC(sel, currentOS); break;
        case 0x04: bankC(sel, currentOS); break;
        case 0x05: bankC(sel, currentOS); break;
        case 0x06: bankC(sel, currentOS); break;
        case 0x07: bankC(sel, currentOS); break;
        case 0x08: bankC(sel, currentOS); break;
        case 0x09: bankC(sel, currentOS); break;
        case 0x0A: bankC(sel, currentOS); break;
        case 0x0B: bankC(sel, currentOS); break;
        case 0x0C: bankC(sel, currentOS); break;
        case 0x0D: bankC(sel, currentOS); break;
        case 0x0E: bankC(sel, currentOS); break;
        case 0x0F: bankC(sel, currentOS); break;
      }
      break;
  }
}

void loop() {
  for(uint8_t i = 0; i < 16; i++){
    uint8_t select = i << 4;
    PORTF = select;
    analogWrite(LEDOUT, BACKLIGHT_INTENSITY);
    if(digitalRead(KEYIN) == LOW) {
      key(i);
    }
  }
}

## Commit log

2025-03-25 Added the "hardware" folder
    [freeMacro_rev_1-B_Cu.gbl, freeMacro_rev_1-B_Mask.gbs, freeMacro_rev_1-B_Paste.gbp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]
2025-03-25 Added default enclosure files
    [Case Bottom.step, Case Bottom.stl, Case Top.step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]
